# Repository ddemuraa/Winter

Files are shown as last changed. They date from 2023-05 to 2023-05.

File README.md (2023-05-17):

# Winter
2-key Hall effect keypad made for osu! with rapid trigger, dedicated for aespa's member "WINTER" with their newest track "I'm Unhappy"

Designed in KiCad 7.0.2
 
front back

# Features
- Uses [minipad firmware](https://github.com/minipadKB/minipad-firmware)
- Powered using RP2040 with 128MB of flash memory
- Uses SK6812MINI-E for per-key RGBs
- Rapid Trigger with adjustable actuation

# Case
- STL file for 3D print is available in `3D Case file`
- Designed in Fusion 360
- Made into 2 parts
- 2cm tall

# Assembly 
All assembly files for JLCPCB manufacture are available in `Gerber, BOM & CPL`

# WIP
- add photos of pcb IRL

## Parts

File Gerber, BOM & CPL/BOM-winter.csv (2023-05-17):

Comment | Designator | Footprint | LCSC
1k | R1,R4,R7 | R_0402_1005Metric | C11702
AO3401A | Q1 | SOT-23 | C15127
100nF | C11,C12,C13,C14,C15,C16,C17,C18,C19,C5,C7,C8 | C_0402_1005Metric | C1525
10uF | C9 | C_0402_1005Metric | C15525
20pF | C3,C4 | C_0402_1005Metric | C1554
USB_C_12P | USB1 | USB_C_Receptacle_HRO_TYPE-C-31-M-12 | C165948
RP2040 | U1 | RP2040-QFN-56 | C2040
10k | R8,R9 | R_0402_1005Metric | C25086
27 | R2,R3 | R_0603_1608Metric | C25190
5.1k | R5,R6 | R_0402_1005Metric | C25905
Hall_Sensor | K1,K2 | SOT-23 | C2904393
MX_SK6812MINI-E | LED1,LED2 | LED_MX_6028R-ROT | C5149201
1uF | C1,C10,C2,C6 | C_0402_1005Metric | C52923
SRV05-4 | U2 | SOT-23-6-routable | C85364
500mA | F1 | Fuse_0805_2012Metric | C883105
W25Q32JVSS | U4 | SOIC-8_5.23x5.23mm_P1.27mm | C97521
XTAL | Y1 | Crystal_SMD_3225-4Pin_3.2x2.5mm
XC6206PxxxMR | U3 | SOT-23

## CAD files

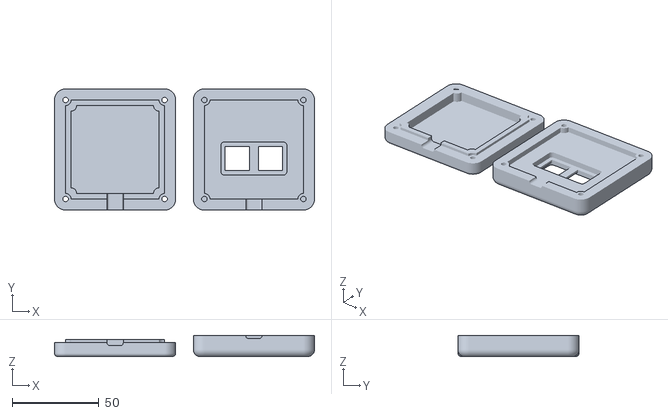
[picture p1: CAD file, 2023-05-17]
3D Case file/winter case.stl
149.9 x 69.9 x 12.2

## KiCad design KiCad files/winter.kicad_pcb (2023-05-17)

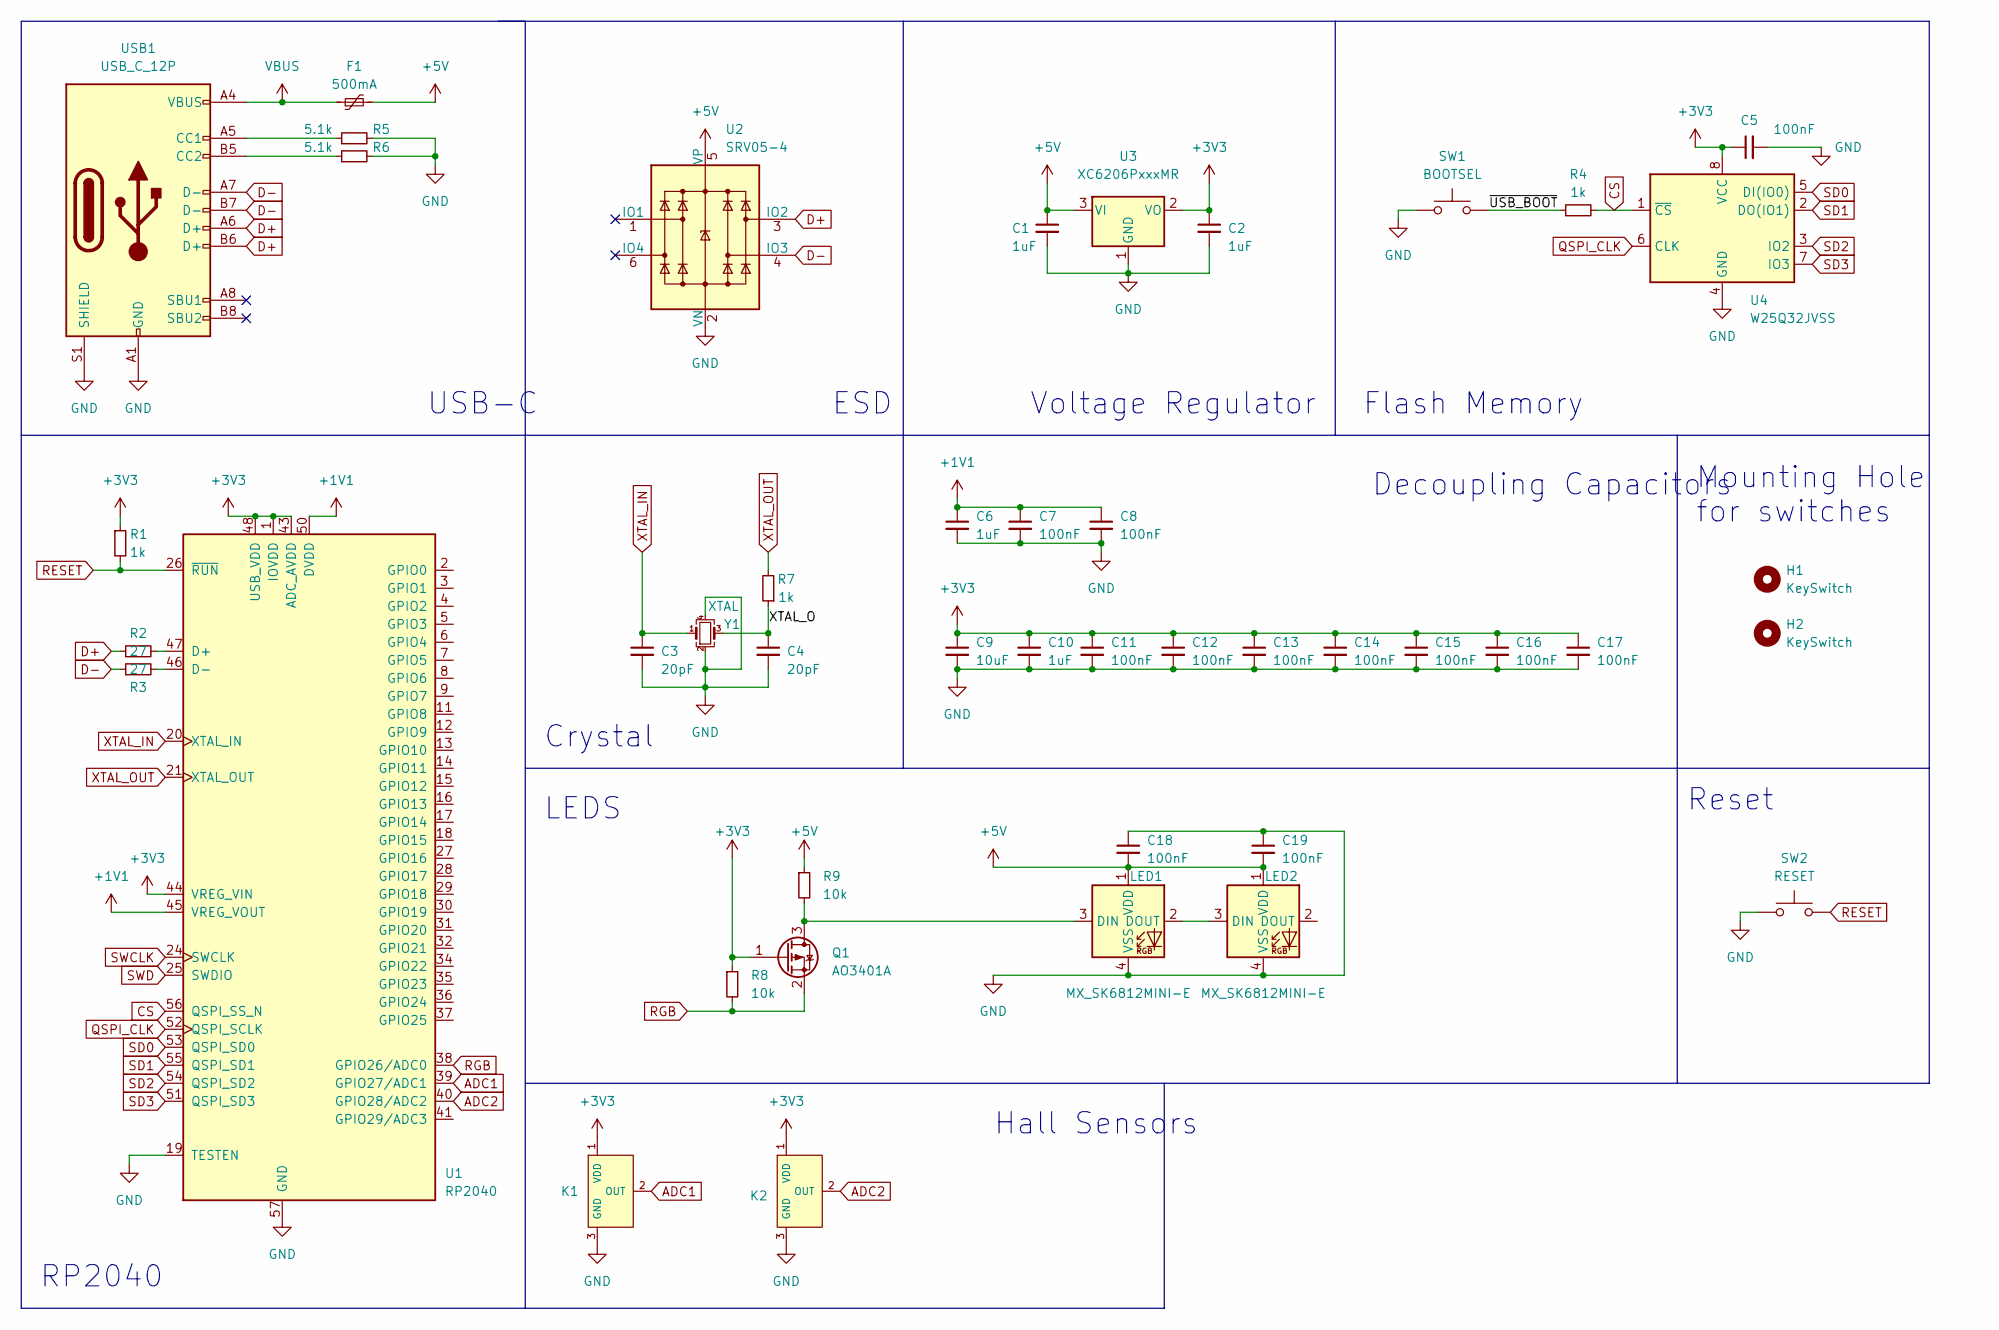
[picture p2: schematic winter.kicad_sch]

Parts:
C1, C2, C6, C10: 1uF; C_0402_1005Metric
C3, C4: 20pF; C_0402_1005Metric
C5, C7, C8, C11, C12, C13, C14, C15, C16, C17, C18, C19: 100nF; C_0402_1005Metric
C9: 10uF; C_0402_1005Metric
F1: 500mA; Fuse_0805_2012Metric
H1, H2: KeySwitch; MXOnly-1U-FLIPPED
K1, K2: Hall_Sensor; SOT-23; MPN GH39FKSW; LCSC Part C266230
LED1, LED2: MX_SK6812MINI-E; LED_MX_6028R-ROT
Q1: AO3401A; SOT-23
R1, R4, R7: 1k; R_0402_1005Metric
R2, R3: 27; R_0603_1608Metric
R5, R6: 5.1k; R_0402_1005Metric
R8, R9: 10k; R_0402_1005Metric
SW1: BOOTSEL; SolderJumper-2_P1.3mm_Bridged_Pad1.0x1.5mm
SW2: RESET; SolderJumper-2_P1.3mm_Bridged_Pad1.0x1.5mm
U1: RP2040; RP2040-QFN-56
U2: SRV05-4; SOT-23-6-routable
U3: XC6206PxxxMR; SOT-23
U4: W25Q32JVSS; SOIC-8_5.23x5.23mm_P1.27mm
USB1: USB_C_12P; USB_C_Receptacle_HRO_TYPE-C-31-M-12
Y1: XTAL; Crystal_SMD_3225-4Pin_3.2x2.5mm

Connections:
+1V1: C6.1, C7.1, C8.1, U1.23 (DVDD), U1.45 (VREG_VOUT), U1.50 (DVDD)
+3V3: C2.1, C5.1, C9.1, C10.1, C11.1, C12.1, C13.1, C14.1, C15.1, C16.1, C17.1, K1.1 (VDD), K2.1 (VDD), Q1.1 (G), R1.1, R8.1, U1.1 (IOVDD), U1.10 (IOVDD), U1.22 (IOVDD), U1.33 (IOVDD), U1.42 (IOVDD), U1.43 (ADC_AVDD), U1.44 (VREG_VIN), U1.48 (USB_VDD), U1.49 (IOVDD), U3.2 (VO), U4.8 (VCC)
+5V: C1.1, C18.2, C19.2, F1.2, LED1.1 (VDD), LED2.1 (VDD), R9.1, U2.5 (VP), U3.3 (VI)
/XTAL_O: C4.1, R7.1, Y1.3
/~USB_BOOT: R4.1, SW1.2
ADC1: K1.2 (OUT), U1.39 (GPIO27/ADC1)
ADC2: K2.2 (OUT), U1.40 (GPIO28/ADC2)
CS: R4.2, U1.56 (QSPI_SS_N), U4.1 (~CS)
D+: R2.1, U2.3 (IO2), USB1.A6 (D+), USB1.B6 (D+)
D-: R3.1, U2.4 (IO3), USB1.A7 (D-), USB1.B7 (D-)
GND: C1.2, C2.2, C3.2, C4.2, C5.2, C6.2, C7.2, C8.2, C9.2, C10.2, C11.2, C12.2, C13.2, C14.2, C15.2, C16.2, C17.2, C18.1, C19.1, K1.3 (GND), K2.3 (GND), LED1.4 (VSS), LED2.4 (VSS), R5.2, R6.2, SW1.1, SW2.1, U1.19 (TESTEN), U1.57 (GND), U2.2 (VN), U3.1 (GND), U4.4 (GND), USB1.A1 (GND), USB1.A12 (GND), USB1.B1 (GND), USB1.B12 (GND), USB1.S1 (SHIELD), Y1.2, Y1.4
unnamed: LED1.3 (DIN), Q1.3 (D), R9.2
unnamed: LED1.2 (DOUT), LED2.3 (DIN)
unnamed: R2.2, U1.47 (D+)
unnamed: R3.2, U1.46 (D-)
unnamed: R5.1, USB1.A5 (CC1)
unnamed: R6.1, USB1.B5 (CC2)
QSPI_CLK: U1.52 (QSPI_SCLK), U4.6 (CLK)
RESET: R1.2, SW2.2, U1.26 (~RUN)
RGB: Q1.2 (S), R8.2, U1.38 (GPIO26/ADC0)
SD0: U1.53 (QSPI_SD0), U4.5 (DI(IO0))
SD1: U1.55 (QSPI_SD1), U4.2 (DO(IO1))
SD2: U1.54 (QSPI_SD2), U4.3 (IO2)
SD3: U1.51 (QSPI_SD3), U4.7 (IO3)
SWCLK: U1.24 (SWCLK)
SWD: U1.25 (SWDIO)
VBUS: F1.1, USB1.A4 (VBUS), USB1.A9 (VBUS), USB1.B4 (VBUS), USB1.B9 (VBUS)
XTAL_IN: C3.1, U1.20 (XTAL_IN), Y1.1
XTAL_OUT: R7.2, U1.21 (XTAL_OUT)

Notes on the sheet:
LEDS
ESD
Hall Sensors
USB-C
Mounting Hole for switches
Decoupling Capacitors
Flash Memory
RP2040
Crystal
Voltage Regulator
Reset

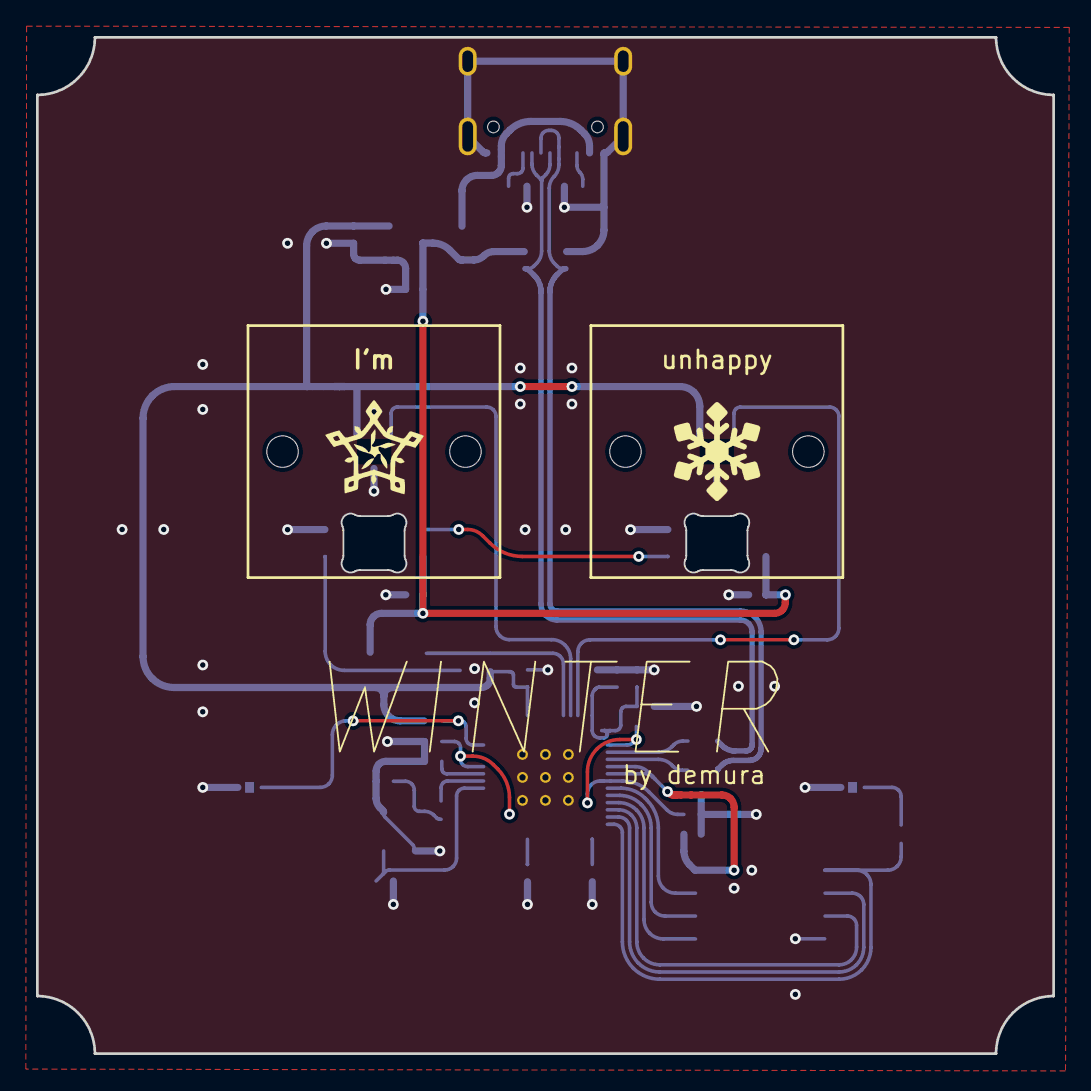
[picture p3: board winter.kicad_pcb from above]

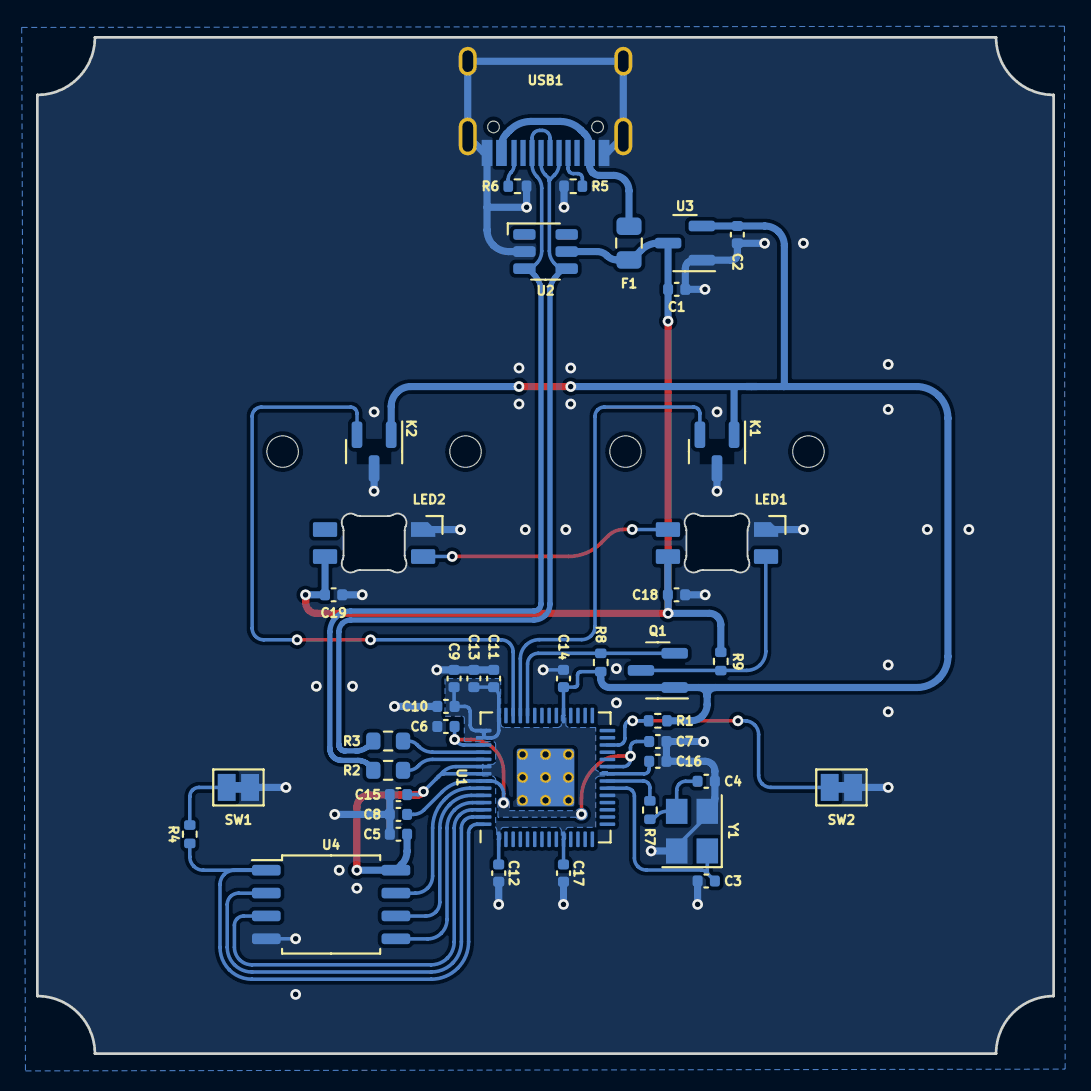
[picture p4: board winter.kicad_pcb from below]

Board: 2 copper layers, 56.5 x 56.5 mm, 44 parts (44 on the bottom side), 27 nets.
